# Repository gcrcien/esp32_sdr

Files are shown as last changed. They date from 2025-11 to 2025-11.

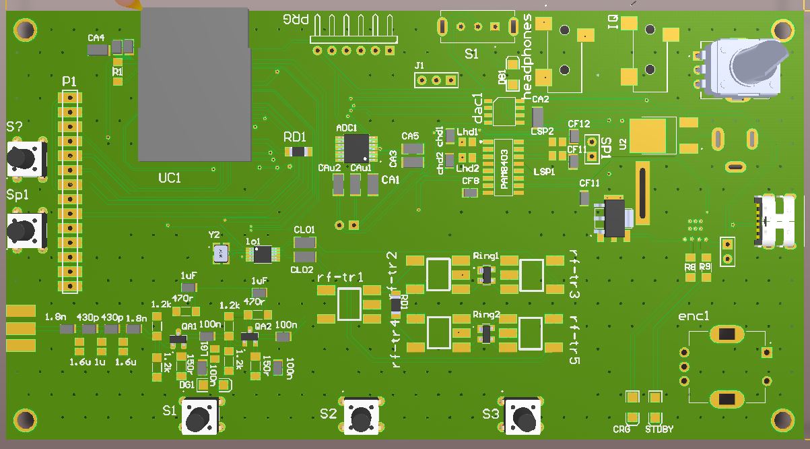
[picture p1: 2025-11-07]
SDRimage1.JPG

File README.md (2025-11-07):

ESP32 Phasing SDR Board

////////////////////////////////////////////////////////////////////////////////

///////This is a work in progress the board and firmware still have bugs////////

////////////////////////////////////////////////////////////////////////////////

Standalone software-defined radio front-end based on an ESP32 and an analog phasing (I/Q) receiver.
The goal of this project is to provide a compact HF SDR/panadapter board with:

Analog RF front-end (ring mixers + handmade transformers)

High-quality 24-bit baseband digitization

On-board audio output and 4" TFT UI

Direct I/Q output for connection to a PC SDR program

The PCB shown here is already fabricated and under test.

Main Features

ESP32-based SDR platform

Runs the demodulation / UI firmware (AM, SSB, CW, etc.).

Communicates with ADC, DAC and TFT over I²S / SPI.

RF front-end

SMA antenna input.

Ring mixers built with BAT01599R Schottky diode quads.

Handmade RF transformers for LO and RF ports.

RF pre-amplifier using a 2N3904.

Baseband section

Active I/Q low-frequency amplification with a TL072 dual op-amp.

I/Q output header for connection to a PC (panadapter / external SDR).

Data conversion

24-bit audio ADC for digitizing baseband 

Audio DAC for speaker/headphone output 

Audio output

On-board audio power stage for speaker or headphones.

Dedicated audio out connector.

User interface

4" TFT display for spectrum / waterfall / UI.

Rotary encoder for tuning and menu navigation.

Multiple push buttons for mode / band / configuration.

Power

USB-C connector for power and data.

On-board PT4056 Li-Ion charger.

Battery connector footprint.

Power switch and status LEDs.

Hardware Overview
RF Section

SMA input connector feeding the RF front-end.

RF pre-amp based on a 2N3904 transistor.

Double-balanced ring mixers using BAT01599R diode quads.

Handmade transformers for:

RF input matching

Local oscillator distribution

I/Q baseband coupling

Baseband & Conversion

TL072 dual op-amp used as baseband (I/Q) amplifier and anti-alias filtering.

I/Q signals:

Routed to the on-board ADC.

Also exposed on a dedicated header to feed an external PC-based SDR.

24-bit audio ADC connected to the ESP32 via I²S.

Audio DAC connected via I²S to drive the audio chain.

Audio & UI

Audio amplifier stage for speaker / headphones.

4" TFT display:

Used to draw FFT / waterfall and UI elements.

Rotary encoder + push buttons for:

Frequency tuning

Band selection

Demodulation mode and settings.

Power Management

PT4056 Li-Ion charger IC.

USB-C connector for charging and powering the board.

Battery connector footprint (single-cell Li-Ion).

Power rails for RF, analog and digital sections with appropriate decoupling.

Firmware

The firmware is written for the ESP32 and includes:

I²S double-buffered capture from the ADC.

I²S audio playback through the DAC.

Demodulation algorithms for AM, SSB and CW using I/Q phasing.

FFT and waterfall display on the 4" TFT.

Encoder and button handling for tuning and configuration.

Optional I/Q streaming to a PC through the I/Q output.

Imagen de WhatsApp 2025-11-06 a las 18 38 44_351f8baf

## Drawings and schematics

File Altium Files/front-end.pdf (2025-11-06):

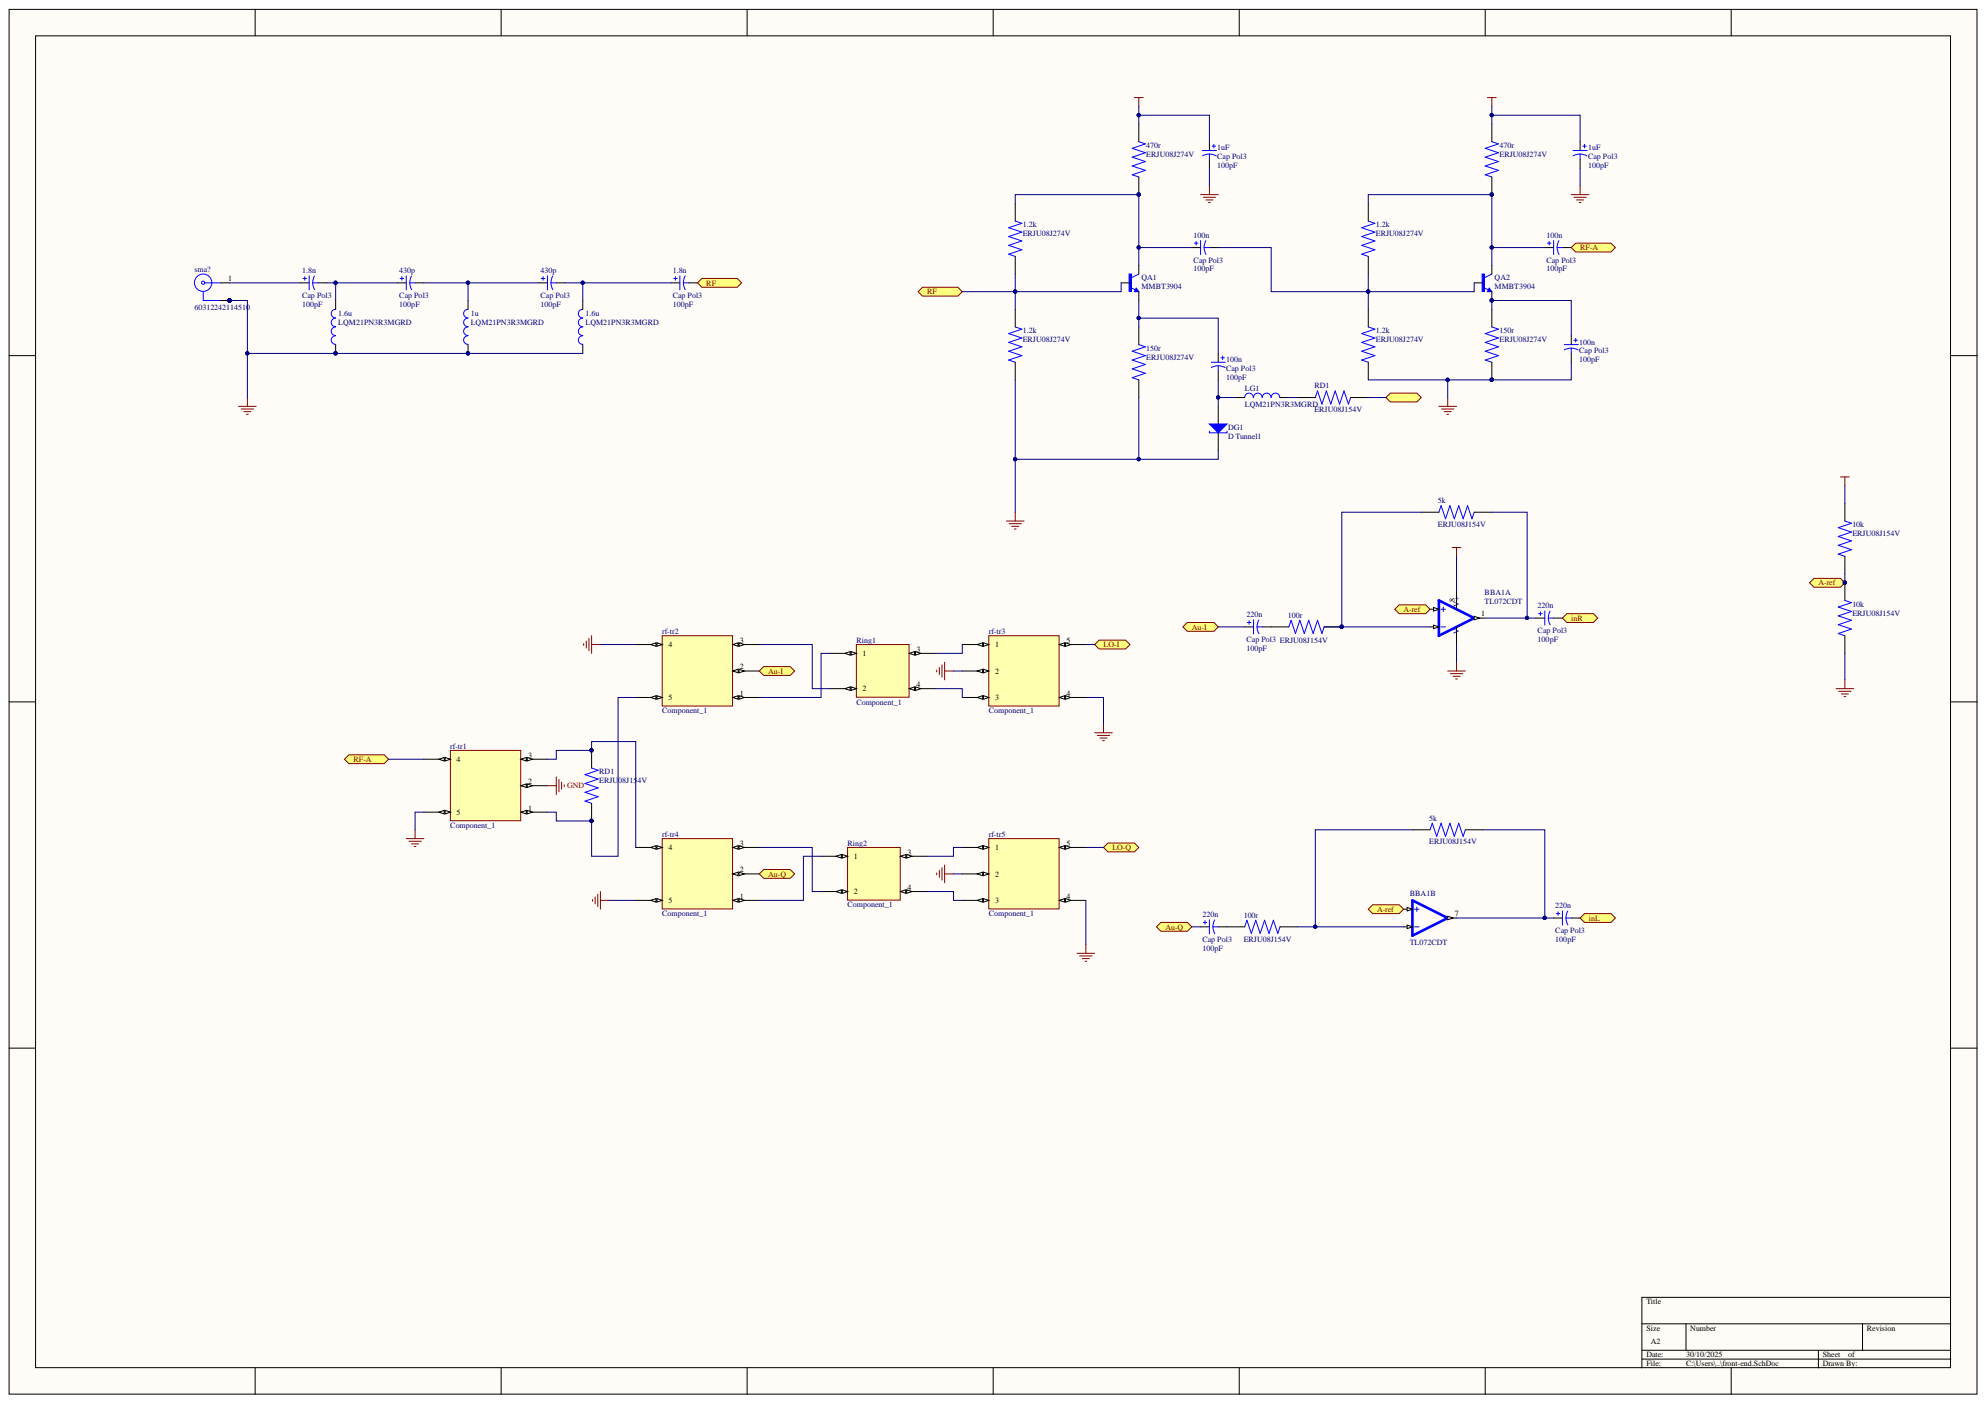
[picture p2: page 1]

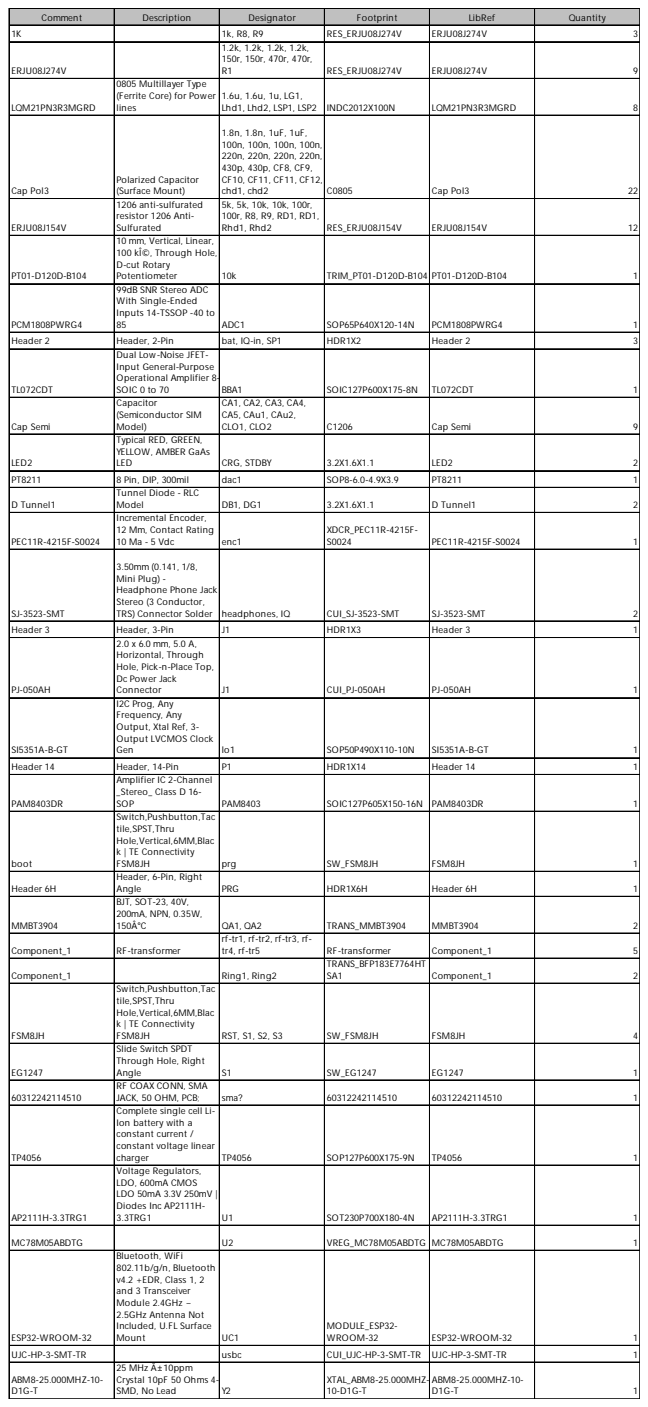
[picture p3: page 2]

Comment | Description | Designator | Footprint | LibRef | Quantity

1K | | 1k, R8, R9 | RES_ERJU08J274V | ERJU08J274V | 3
ERJU08J274V | | 1.2k, 1.2k, 1.2k, 1.2k, 150r, 150r, 470r, 470r, R1 | RES_ERJU08J274V | ERJU08J274V | 9

LQM21PN3R3MGRD | 0805 Multillayer Type (Ferrite Core) for Power lines | 1.6u, 1.6u, 1u, LG1, Lhd1, Lhd2, LSP1, LSP2 | INDC2012X100N | LQM21PN3R3MGRD | 8

Cap Pol3 | Polarized Capacitor (Surface Mount) | 1.8n, 1.8n, 1uF, 1uF, 100n, 100n, 100n, 100n, 220n, 220n, 220n, 220n, 430p, 430p, CF8, CF9, CF10, CF11, CF11, CF12, chd1, chd2 | C0805 | Cap Pol3 | 22

ERJU08J154V | 1206 anti-sulfurated resistor 1206 Anti-Sulfurated | 5k, 5k, 10k, 10k, 100r, 100r, R8, R9, RD1, RD1, Rhd1, Rhd2 | RES_ERJU08J154V | ERJU08J154V | 12

PT01-D120D-B104 | 10 mm, Vertical, Linear, 100 kÎ©, Through Hole, D-cut Rotary Potentiometer | 10k | TRIM_PT01-D120D-B104 | PT01-D120D-B104 | 1

PCM1808PWRG4 | 99dB SNR Stereo ADC With Single-Ended Inputs 14-TSSOP -40 to 85 | ADC1 | SOP65P640X120-14N | PCM1808PWRG4 | 1

Header 2 | Header, 2-Pin | bat, IQ-in, SP1 | HDR1X2 | Header 2 | 3
TL072CDT | Dual Low-Noise JFET-Input General-Purpose Operational Amplifier 8-SOIC 0 to 70 | BBA1 | SOIC127P600X175-8N | TL072CDT | 1

Cap Semi | Capacitor (Semiconductor SIM Model) | CA1, CA2, CA3, CA4, CA5, CAu1, CAu2, CLO1, CLO2 | C1206 | Cap Semi | 9

LED2 | Typical RED, GREEN, YELLOW, AMBER GaAs LED | CRG, STDBY | 3.2X1.6X1.1 | LED2 | 2

PT8211 | 8 Pin, DIP, 300mil | dac1 | SOP8-6.0-4.9X3.9 | PT8211 | 1
D Tunnel1 | Tunnel Diode - RLC Model | DB1, DG1 | 3.2X1.6X1.1 | D Tunnel1 | 2

PEC11R-4215F-S0024 | Incremental Encoder, 12 Mm, Contact Rating 10 Ma - 5 Vdc | enc1 | XDCR_PEC11R-4215F-S0024 | PEC11R-4215F-S0024 | 1

SJ-3523-SMT | 3.50mm (0.141, 1/8, Mini Plug) -Headphone Phone Jack Stereo (3 Conductor, TRS) Connector Solder | headphones, IQ | CUI_SJ-3523-SMT | SJ-3523-SMT | 2

Header 3 | Header, 3-Pin | J1 | HDR1X3 | Header 3 | 1
PJ-050AH | 2.0 x 6.0 mm, 5.0 A, Horizontal, Through Hole, Pick-n-Place Top, Dc Power Jack Connector | J1 | CUI_PJ-050AH | PJ-050AH | 1

SI5351A-B-GT | I2C Prog, Any Frequency, Any Output, Xtal Ref, 3-Output LVCMOS Clock Gen | lo1 | SOP50P490X110-10N | SI5351A-B-GT | 1

Header 14 | Header, 14-Pin | P1 | HDR1X14 | Header 14 | 1
PAM8403DR | Amplifier IC 2-Channel _Stereo_ Class D 16-SOP | PAM8403 | SOIC127P605X150-16N | PAM8403DR | 1

boot | Switch,Pushbutton,Tac tile,SPST,Thru Hole,Vertical,6MM,Blac k | TE Connectivity FSM8JH | prg | SW_FSM8JH | FSM8JH | 1

Header 6H | Header, 6-Pin, Right Angle | PRG | HDR1X6H | Header 6H | 1

MMBT3904 | BJT, SOT-23, 40V, 200mA, NPN, 0.35W, 150Â°C | QA1, QA2 | TRANS_MMBT3904 | MMBT3904 | 2

Component_1 | RF-transformer | rf-tr1, rf-tr2, rf-tr3, rf-tr4, rf-tr5 | RF-transformer | Component_1 | 5

Component_1 | | Ring1, Ring2 | TRANS_BFP183E7764HT SA1 | Component_1 | 2

FSM8JH | Switch,Pushbutton,Tac tile,SPST,Thru Hole,Vertical,6MM,Blac k | TE Connectivity FSM8JH | RST, S1, S2, S3 | SW_FSM8JH | FSM8JH | 4

EG1247 | Slide Switch SPDT Through Hole, Right Angle | S1 | SW_EG1247 | EG1247 | 1

60312242114510 | RF COAX CONN, SMA JACK, 50 OHM, PCB; | sma? | 60312242114510 | 60312242114510 | 1

TP4056 | Complete single cell Li-Ion battery with a constant current / constant voltage linear charger | TP4056 | SOP127P600X175-9N | TP4056 | 1

AP2111H-3.3TRG1 | Voltage Regulators, LDO, 600mA CMOS LDO 50mA 3.3V 250mV | Diodes Inc AP2111H-3.3TRG1 | U1 | SOT230P700X180-4N | AP2111H-3.3TRG1 | 1

MC78M05ABDTG | | U2 | VREG_MC78M05ABDTG | MC78M05ABDTG | 1
ESP32-WROOM-32 | Bluetooth, WiFi 802.11b/g/n, Bluetooth v4.2 +EDR, Class 1, 2 and 3 Transceiver Module 2.4GHz ~ 2.5GHz Antenna Not Included, U.FL Surface Mount | UC1 | MODULE_ESP32-WROOM-32 | ESP32-WROOM-32 | 1

UJC-HP-3-SMT-TR | | usbc | CUI_UJC-HP-3-SMT-TR | UJC-HP-3-SMT-TR | 1
ABM8-25.000MHZ-10-D1G-T | 25 MHz Â±10ppm Crystal 10pF 50 Ohms 4-SMD, No Lead | Y2 | XTAL_ABM8-25.000MHZ-10-D1G-T | ABM8-25.000MHZ-10-D1G-T | 1

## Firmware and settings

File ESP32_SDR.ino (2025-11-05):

// ====================== ESP32_SDR.ino ======================
#include <Arduino.h>

#include "Config.h"
#include "Globals.h"
#include "Storage.h"
#include "Bands.h"
#include "Si5351_IQ.h"
#include "DisplayUI.h"

// bandera global para avisar que cambió la FS
volatile bool g_samplingChanged = false;

#include "I2S_Capture.h"    // versión con doble buffer y frame counter


// 👇👇👇  WRAPPER para el encoder (lo estaba pidiendo)
// Encoder.h llama a sdr_set_sampling(hz), así que lo definimos aquí.
void sdr_set_sampling(uint32_t hz)
{
  // RX (PCM1808) sigue usando Fs variable (span)
  i2s_set_clk(
      I2S_PORT,
      hz,
      I2S_BITS_PER_SAMPLE_32BIT,
      I2S_CHANNEL_STEREO
  );

#if AUDIO_PASSTHROUGH
  // TX (PT8211) SIEMPRE a Fs fija de audio (24 kHz)
  i2s_set_clk(
      I2S_TX_PORT,
      AUDIO_FS_HZ,
      I2S_BITS_PER_SAMPLE_16BIT,
      I2S_CHANNEL_STEREO
  );
#endif

  // actualizar globales (Fs ADC)
  g_samplingHz      = hz;
  g_samplingChanged = true;

  // filtros SIEMPRE diseñados para AUDIO_FS_HZ (24 kHz)
  audio_filters_init((float)AUDIO_FS_HZ);
}




#include "FFT_IQ.h"
#include "Encoder.h"
#include "Layout.h"

TaskHandle_t g_uiTaskHandle = nullptr;
static uint32_t g_uiNotifyDiv = 0;

// ============================================================
//                TAREA DE UI (CORE 0)
// ============================================================
void uiTask(void *pv)
{
  bool layout_fixed = false;

  static double iqR[NUM_SAMPLES];
  static double iqI[NUM_SAMPLES];
  static uint32_t lastFrameId = 0;

  for (;;) {
    // espera a que el core de audio le diga "ya hay frame"
    ulTaskNotifyTake(pdTRUE, portMAX_DELAY);

    // primera vez: arma layout completo
    if (!layout_fixed) {
      layout_setWaterfallTop(180);   // WF abajo
      layout_fixed = true;
    }

    // si cambió la Fs → redibuja todo (ticks, barra, escala, zona FFT, WF)
    if (g_samplingChanged) {
      g_samplingChanged = false;
      layout_setWaterfallTop(180);
    }

    // copiar último frame IQ del core de audio
    uint32_t frameId = 0;
    if (!i2s_copy_latest_iq(iqR, iqI, frameId)) {
      vTaskDelay(1);
      continue;
    }

    // si es el mismo frame que el anterior (pasa en 24k) → no procesar
    if (frameId == lastFrameId) {
      vTaskDelay(1);
      continue;
    }
    lastFrameId = frameId;

    // copiar al buffer real de la FFT (solo la UI toca vReal/vImag)
    for (int i = 0; i < NUM_SAMPLES; i++) {
      vReal[i] = iqR[i];
      vImag[i] = iqI[i];
    }

    // entradas / UI
    enc_pollEncoder();
    enc_pollBandButton();
    bands_select_from_lo(g_loHz);
    ui_drawTopDynamic();

    // ====== FFT COMPLETA ======
    fft_applyWindowIQ();
    fft_runComplex();
    fft_packToDisplay();

fft_autoRef();


    // ====== DIBUJO ======
    ui_drawFFTLine();
    ui_drawWaterfallLine();

    vTaskDelay(1);
  }
}

// ============================================================
//                        SETUP
// ============================================================
void setup()
{
  Serial.begin(115200);
  delay(200);
  //sdr_silence_logs();   // si lo tienes

  // entradas
  pinMode(BAND_SW_PIN, INPUT_PULLUP);
  enc_setup();

  // TFT
  tft.init();
  tft.setRotation(3);
  ui_initDisplay();
  ui_drawTopStaticTicks();
  ui_initWaterfall();
  layout_setWaterfallTop(180);

  // EEPROM / storage
  ee_begin();
  ee_load_or_defaults();

  // bandas
  bands_select_from_lo(g_loHz);

  // Si5351
  si_init();

  g_lastApplyMs = 0;
  si_applyIfDue();

  // I2S con el FS actual (de Globals.h)
  i2s_setup();

  // tarea de UI en core 0
  xTaskCreatePinnedToCore(
      uiTask,
      "uiTask",
      8192,
      nullptr,
      1,
      &g_uiTaskHandle,
      0   // core 0
  );
}

// ============================================================
//                        LOOP (CORE 1)
// ============================================================
void loop()
{
  // captura IQ → llena doble buffer
  i2s_captureIQ();

  // despertar a la UI cada 2 capturas
  if (g_uiTaskHandle) {
    g_uiNotifyDiv++;
    if (g_uiNotifyDiv & 0x1) {
      xTaskNotifyGive(g_uiTaskHandle);
    }
  }

  // tareas de baja frecuencia
  si_applyIfDue();
  ee_maybe_commit();
}

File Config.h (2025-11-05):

// Config.h
#ifndef CONFIG_H
#define CONFIG_H

#include <Arduino.h>
#include <TFT_eSPI.h>
#include <SPI.h>
#include <Wire.h>
#include <si5351.h>
#include <EEPROM.h>
#include <driver/i2s.h>
#include <math.h>

// ================== LAYOUT GENERAL ==================
// Subimos la barra porque en DisplayUI usamos FONT7 (~48 px)
#define TOPBAR_H               52    // antes 18
// barra de bandas (debajo de la topbar)
#define BANDBAR_H              14
// alto fijo de la FFT (lo usan DisplayUI.h y Layout.h)
#define FFT_FIXED_H            140
// separación entre FFT y waterfall
#define FFT_WF_GAP             0
// barra de escala (la que dibuja marcas de frecuencia)
#define SCALEBAR_H             14

// waterfall
#define DRAW_WIDTH             480
#define WATERFALL_HEIGHT       80
#define WATERFALL_WIDTH        DRAW_WIDTH

// Top de la escala en dB (relativo a REF)
#define UI_DB_TOP   -15.0f       // 0 dB = pico a nivel REF
// Span de la escala (cuántos dB se muestran hacia abajo)
#define UI_DB_SPAN  20.0f      // prueba 40, 50, 60...

// ================== MUESTRAS / FFT ==================
#define NUM_SAMPLES            512

// ================== P I N E S ==================
// encoder
#define ENC_A                  33
#define ENC_B                  27
#define ENC_SW                 32

// botón de bandas
#define BAND_SW_PIN            16
#define BAND_LONG_MS           500

// selector extra
#define S1_PIN                 14

// ================== I2S ==================
#define I2S_PORT               I2S_NUM_0
#define I2S_BCK_PIN            26
#define I2S_LRCK_PIN           25
#define I2S_DATA_PIN           17
#define I2S_MCLK_PIN           0
#define USE_APLL               true

// ==== I2S TX (DAC externo) ====
#define I2S_TX_PORT      I2S_NUM_1
#define I2S_TX_BCK_PIN   13   // gpio13 > bck
#define I2S_TX_WS_PIN    12   // gpio12 > ws
#define I2S_TX_DATA_PIN  5    // gpio5  > din
#define AUDIO_FS_HZ          24000U   // Fs fija para DAC y filtros de audio
// ================== EEPROM ==================
#define EEPROM_BYTES           64
#define EE_MAGIC_ADDR          0
#define EE_MAGIC_VAL           0x53445231UL
#define EE_LO_ADDR             4
#define EE_REF_ADDR            8

// nuevos para IQ
#define EE_IQGAIN_ADDR         12     // double → 12..19
#define EE_IQPHASE_ADDR        20     // double → 20..27

// ================== Encoder ==================
#define ENC_COUNTS_PER_DETENT  4
#define DC_MAX_MS              350

// ================== Modo encoder ==================
enum {
  ENC_MODE_NORMAL = 0,
  ENC_MODE_IQ_GAIN,
  ENC_MODE_IQ_PHASE
};

#endif // CONFIG_H

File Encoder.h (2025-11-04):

// Encoder.h
#ifndef ENCODER_H
#define ENCODER_H

#include <Arduino.h>
#include "Config.h"
#include "Globals.h"
#include "Storage.h"
#include "Bands.h"

// ================== externs del proyecto ==================
extern void ee_set_lo(uint32_t hz);
extern void ee_set_ref(uint32_t hz);
extern void ee_set_iq_gain(double g);
extern void ee_set_iq_phase(double ph);
extern void bands_select_from_lo(uint32_t hz);
extern void bands_next_band();
extern void ui_drawBandBar();
extern void ui_drawTopDynamic();

extern uint32_t g_loHz;
extern uint32_t g_refMag;
extern int      g_bandIndex;
extern int      g_encMode;     // ENC_MODE_NORMAL / ENC_MODE_IQ_GAIN / ENC_MODE_IQ_PHASE
extern double   g_iqGain;
extern double   g_iqPhase;

extern const uint32_t STEP_TABLE[];
extern int            g_stepIdx;

// sampleo (S1)
extern const uint32_t g_samplingTable[3];
extern int      g_samplingIndex;
extern uint32_t g_samplingHz;
void sdr_set_sampling(uint32_t hz);

// demod (nuevo)
extern uint8_t g_demodMode;
#ifndef DEMOD_COUNT
#define DEMOD_COUNT 4   // AM, LSB, USB, DSB
#endif

// ================== pines por defecto ==================
#ifndef ENC_A
#define ENC_A 33
#endif
#ifndef ENC_B
#define ENC_B 27
#endif
#ifndef ENC_SW
#define ENC_SW 32
#endif
#ifndef BAND_SW_PIN
#define BAND_SW_PIN 16     // S2
#endif
#ifndef S1_PIN
#define S1_PIN 17
#endif
#ifndef BAND_LONG_MS
#define BAND_LONG_MS 600
#endif

// ================== selección de driver ==================
// 1 = tu driver original con LUT (mejor resolución)
// 0 = driver simple: interrupción en A y se lee B
#ifndef ENC_DRIVER_MODE
#define ENC_DRIVER_MODE 1
#endif

// tiempo mínimo entre IRQ para no reventar la CPU
#ifndef ENC_ISR_MIN_US
#define ENC_ISR_MIN_US 60     // antes estaba en ~120 us
#endif

// =========================================================
// 1) DRIVER 1: Encoder por LUT (tu original) PERO:
//    - debounce configurable
//    - NO se pierden cuartos (guarda el residuo)
// =========================================================
#if ENC_DRIVER_MODE == 1

static volatile int8_t   s_enc_quarters = 0;
static volatile uint8_t  s_enc_prev_ab  = 0;
static volatile uint32_t s_enc_last_us  = 0;

// LUT de 16 estados
static const int8_t ENC_LUT[16] = {
  0, -1, +1, 0,
  +1, 0, 0, -1,
  -1, 0, 0, +1,
  0, +1, -1, 0
};

// 👉 OJO: SIN IRAM_ATTR para evitar el “dangerous relocation”
void enc_isr()
{
  uint32_t now = micros();
  if ((now - s_enc_last_us) < ENC_ISR_MIN_US) return;
  s_enc_last_us = now;

  uint8_t a = (uint8_t)digitalRead(ENC_A);
  uint8_t b = (uint8_t)digitalRead(ENC_B);

  uint8_t curr = (a ? 1 : 0) | (b ? 2 : 0);
  uint8_t idx  = (s_enc_prev_ab << 2) | curr;
  int8_t  d    = ENC_LUT[idx];
  if (d != 0) {
    s_enc_quarters += d;
  }
  s_enc_prev_ab = curr;
}

#endif // ENC_DRIVER_MODE == 1

// =========================================================
// 2) DRIVER 0: Encoder simple (IRQ en A → leo B)
//    - menos interrupciones
//    - no hay LUT
// =========================================================
#if ENC_DRIVER_MODE == 0

static volatile int16_t s_enc_delta = 0;
static volatile uint32_t s_enc_last_us = 0;

void enc_isr_a()
{
  uint32_t now = micros();
  if ((now - s_enc_last_us) < ENC_ISR_MIN_US) return;
  s_enc_last_us = now;

  // lee el otro canal
  bool b = (digitalRead(ENC_B) != 0);
  if (b) s_enc_delta++;   // un sentido
  else   s_enc_delta--;   // el otro
}

#endif // ENC_DRIVER_MODE == 0

// =====================================================
// 3) setup (común)
// =====================================================
inline void enc_setup()
{
  pinMode(ENC_A, INPUT_PULLUP);
  pinMode(ENC_B, INPUT_PULLUP);
  pinMode(ENC_SW, INPUT_PULLUP);
  pinMode(BAND_SW_PIN, INPUT_PULLUP);
  pinMode(S1_PIN, INPUT_PULLUP);

#if ENC_DRIVER_MODE == 1
  // inicializa estado previo
  uint8_t a = (uint8_t)digitalRead(ENC_A);
  uint8_t b = (uint8_t)digitalRead(ENC_B);
  s_enc_prev_ab = (a ? 1 : 0) | (b ? 2 : 0);

  attachInterrupt(digitalPinToInterrupt(ENC_A), enc_isr, CHANGE);
  attachInterrupt(digitalPinToInterrupt(ENC_B), enc_isr, CHANGE);

#else
  // modo simple: solo A
  attachInterrupt(digitalPinToInterrupt(ENC_A), enc_isr_a, CHANGE);
#endif
}

// =====================================================
// 4) Botón de banda (S2)
//     - short → siguiente banda
//     - long  → siguiente MODO de demod
// =====================================================
inline void enc_pollBandButton()
{
  static int      prevBtn   = HIGH;
  static uint32_t pressMs   = 0;
  static bool     longFired = false;

  int nowBtn = digitalRead(BAND_SW_PIN);

  // flanco de bajada
  if (prevBtn == HIGH && nowBtn == LOW) {
    pressMs   = millis();
    longFired = false;
  }

  // sigue presionado
  if (prevBtn == LOW && nowBtn == LOW) {
    if (!longFired && (millis() - pressMs) >= BAND_LONG_MS) {
      longFired = true;

      // long → demod
      g_demodMode++;
      if (g_demodMode >= DEMOD_COUNT)
        g_demodMode = 0;

      ui_drawTopDynamic();
      ui_drawBandBar();
    }
  }

  // flanco de subida
  if (prevBtn == LOW && nowBtn == HIGH) {
    uint32_t dur = millis() - pressMs;
    if (dur < BAND_LONG_MS && !longFired) {
      // short → banda
      bands_next_band();
      ui_drawBandBar();
    }
  }

  prevBtn = nowBtn;
}

// =====================================================
// 5) poll principal (lo llama tu uiTask())
//     aquí metemos el "no pierdas cuartos"
// =====================================================
inline void enc_pollEncoder()
{
  // primero S2
  enc_pollBandButton();

  // S1 (cambiar sample rate)
  {
    static bool     s1Prev = false;
    static uint32_t s1Down = 0;
    bool s1Now = (digitalRead(S1_PIN) == LOW);

    if (!s1Prev && s1Now) {
      s1Down = millis();
    }
    if (s1Prev && !s1Now) {
      uint32_t dur = millis() - s1Down;
      if (dur < 250) {
        g_samplingIndex++;
        if (g_samplingIndex >= 3) g_samplingIndex = 0;
        g_samplingHz = g_samplingTable[g_samplingIndex];
        sdr_set_sampling(g_samplingHz);
      }
    }
    s1Prev = s1Now;
  }

  // ==================== LECTURA DEL ENCODER ====================
  int16_t steps = 0;

#if ENC_DRIVER_MODE == 1
  // ---- modo LUT: tenemos cuartos → los acumulamos sin perderlos
  static int8_t s_quarter_rem = 0;
  int8_t quarters;
  noInterrupts();
  quarters = s_enc_quarters;
  s_enc_quarters = 0;
  interrupts();

  quarters += s_quarter_rem;     // agrega lo que sobró antes
  steps = quarters / 4;          // pasos completos
  s_quarter_rem = quarters % 4;  // guarda el residuo (0..3 o 0..-3)
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

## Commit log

2025-11-02 First funcrional waterfall version
    First complex waterfall with no demod yet, ADC sample rates 24, 48 & 96ks/S , (ADC is capable of up to 250kss)
2025-11-04 ESP32 SDR with audio passtrhough
    Managed to activate the audio pipeline, achieving audio passthrough from the ADC>ESP32>DAC>Audio amp(no DSP yet)
2025-11-05 Fucntional SSB demod
    added some filtering, included functional SSB demod
2025-11-06 better filtering
    eliminated noise close to0 frequency and cleaned the audio immensely
    [I2S_Capture.h]
2025-11-06 Update filtering chain
    previous version had a lot of aliasing due to not cleaning the raw data before decimation/procesing, included a filter that prevents this from happening
    [I2S_Capture.h]
2025-11-06 housekeeping, filter adjustment and other stuff
2025-11-06 Included Altium Files
    [Diode-ring.SchLib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]
2025-11-07 Add README.md for ESP32 Phasing SDR Board
    Added detailed project description and hardware overview for the ESP32 Phasing SDR Board.
